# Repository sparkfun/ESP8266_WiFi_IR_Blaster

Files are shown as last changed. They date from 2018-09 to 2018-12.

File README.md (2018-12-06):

SparkFun WiFi IR Blaster (ESP8266)
========================================

SparkFun ESP8266 WiFi IR Blaster (https://www.sparkfun.com/products/15031)

[*SparkFun ESP8266 WiFi IR Blaster (DEV-15031)*](https://www.sparkfun.com/products/15031)

The WiFi IR Blaster is designed to connect all of your old, legacy IR-controlled devices to a WiFi network -- exposing them to a new method of control. Want to control your TV via a web-browser? Want to ask Alexa to mute your stereo? Want to schedule triggers to your IR-controlled LED strip? These are all applications that the WiFi IR Blaster is perfect for.

The WiFi IR Blaster combines an ESP8266 -- a powerful WiFi/microcontroller SoC -- with an IR emitter and receiver. With built-in WiFi support, the ESP8266 can be programmed to provide an interface between HTTP, MQTT, TCP, and UDP services and infrared-controlled devices.

This product includes the WiFi IR Blaster, a [Lite-ON LTE-302](https://www.sparkfun.com/datasheets/Components/LTE-302.pdf) infrared emitter, and a [TSOP38238 IR receiver](https://www.sparkfun.com/products/10266). The IR emitter and detector are not populated on the board -- allowing you to assemble them in any orientation your project requires.

For help getting started, check out our [WiFi IR Blaster Hookup Guide](https://learn.sparkfun.com/tutorials/wifi-ir-blaster-hookup-guide), which explains how to assemble the board, program it, and use the [IRremoteESP8266](https://github.com/markszabo/IRremoteESP8266) Arduino library.

SparkFun labored with love to create this code. Feel like supporting open source hardware? 
Buy a [breakout board](https://www.sparkfun.com/products/15000) from SparkFun!

Repository Contents
-------------------

* **/Documents** - Datasheets
* **/Hardware** - Eagle design files (.brd, .sch)
* **/Production** - Production panel files (.brd)

Documentation
--------------

* **[Hookup Guide](https://learn.sparkfun.com/tutorials/sparkfun-wifi-ir-blaster-hookup-guide)** - Basic hookup guide.

License Information
-------------------

This product is _**open source**_! 

If you have any questions or concerns on licensing, please contact techsupport@sparkfun.com.

Please use, reuse, and modify these files as you see fit. Please maintain attribution to SparkFun Electronics and release any derivative under the same license.

Distributed as-is; no warranty is given.

- Your friends at SparkFun.

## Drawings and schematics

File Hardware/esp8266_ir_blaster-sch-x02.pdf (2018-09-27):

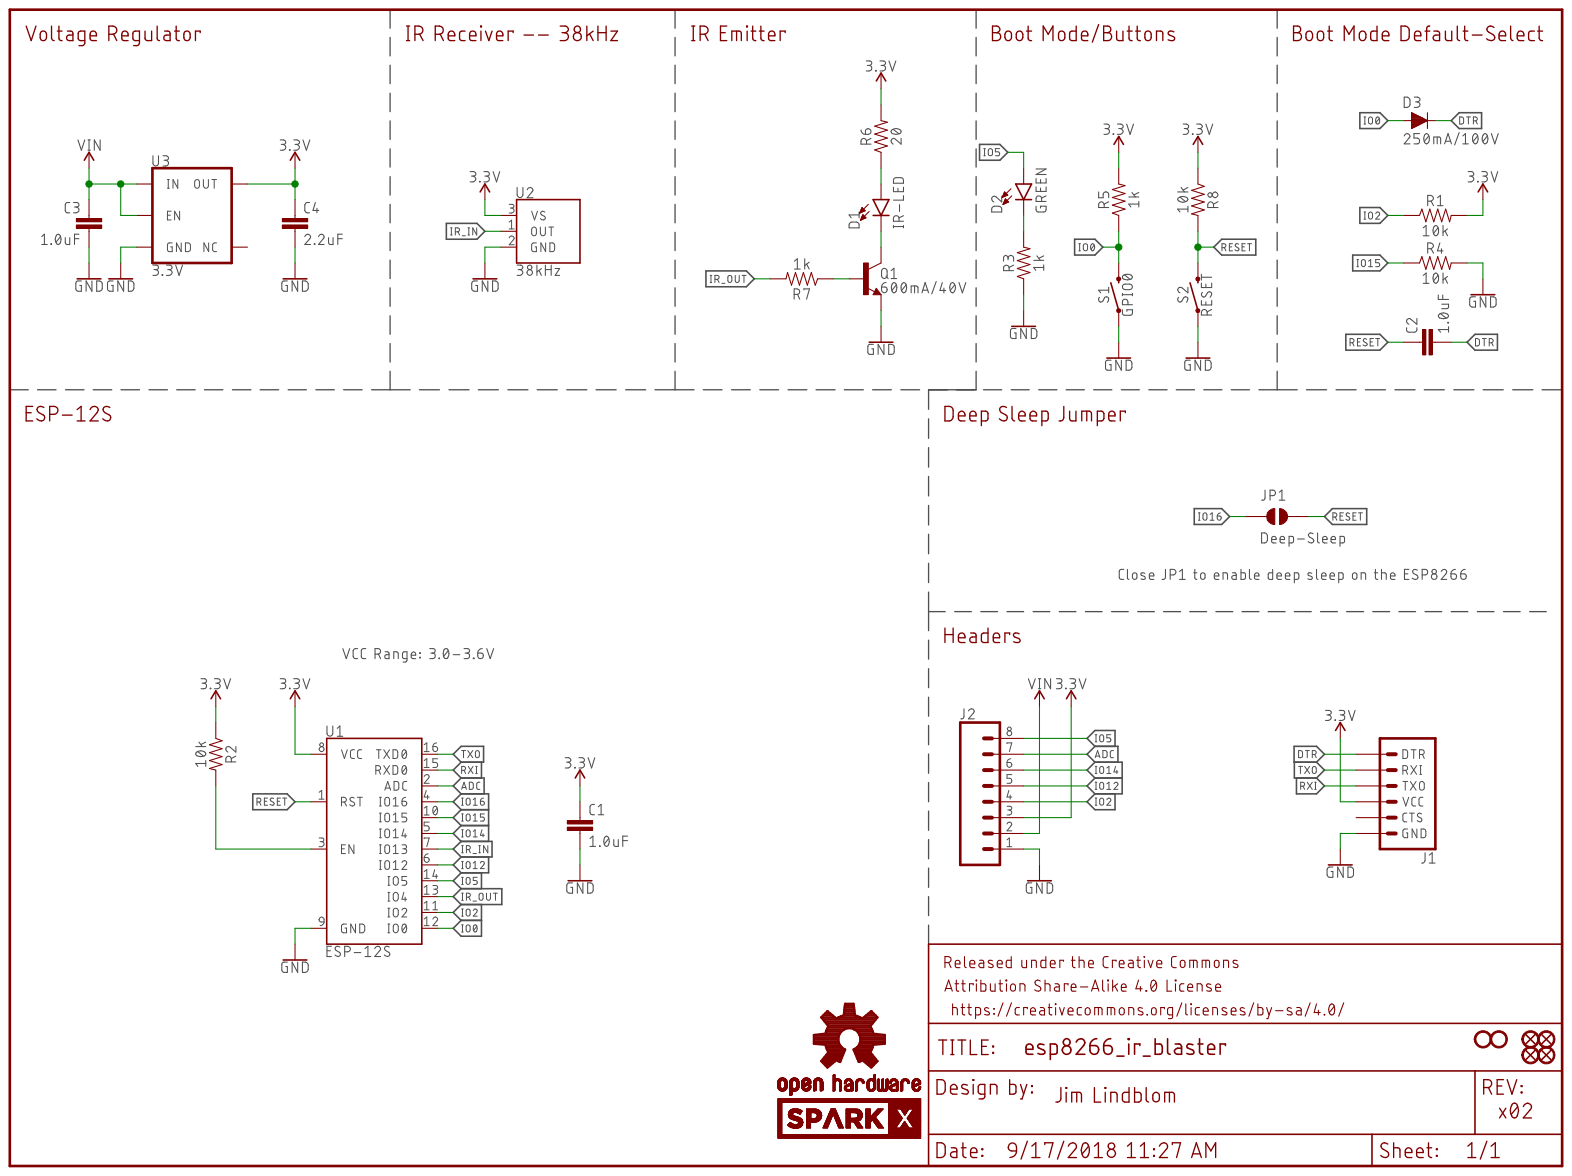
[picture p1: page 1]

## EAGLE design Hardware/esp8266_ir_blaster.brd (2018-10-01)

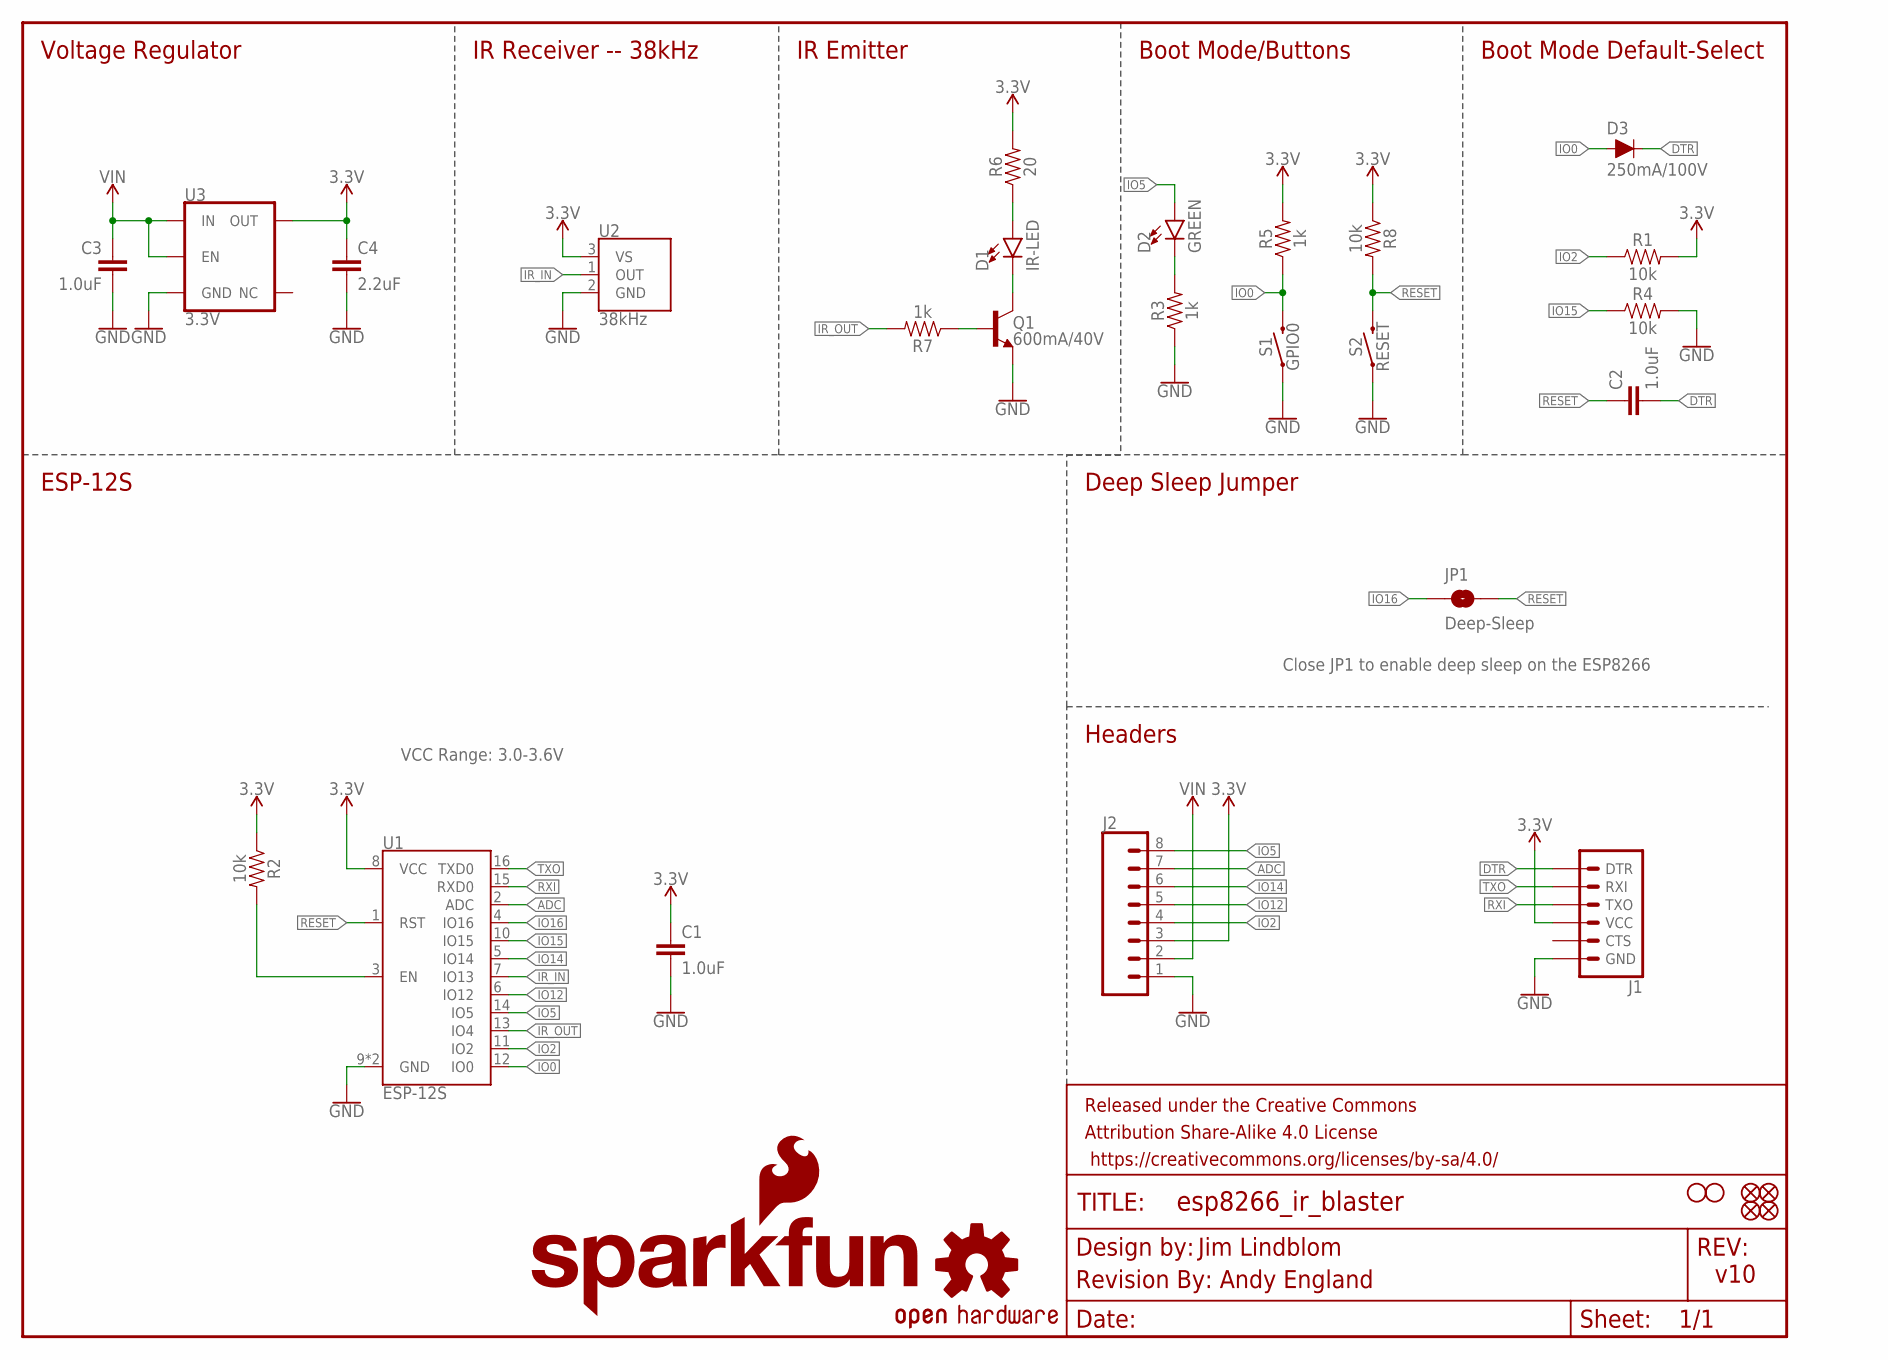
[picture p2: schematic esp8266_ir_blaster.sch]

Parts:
C1, C2, C3: 1.0uF; 0603
C4: 2.2uF; 0603
D1: IR-LED; LTE-302
D2: GREEN; LED-0603
D3: 250mA/100V; SOD-323
FD1, FD2, FD3, FD4: FIDUCIALUFIDUCIAL; FIDUCIAL-MICRO
FRAME1: FRAME-LETTER; CREATIVE_COMMONS
H1, H2: STAND-OFF
J1: 6_PIN_SERIAL_TARGETNO_SILK; 1X06_NO_SILK
J2: CONN_08NO_SILK_FEMALE_PTH; 1X08_NO_SILK
JP1: Deep-Sleep; SMT-JUMPER_2_NO_NO-SILK
LOGO1: OSHW-LOGOS; OSHW-LOGO-S
LOGO2: SFE_LOGO_NAME_FLAME.1_INCH; SFE_LOGO_NAME_FLAME_.1
LOGO3: REVISION
Q1: 600mA/40V; SOT23-3
R1, R2, R4, R8: 10k; 0603
R3, R5, R7: 1k; 0603
R6: 20; 0603
S1: GPIO0; TACTILE_SWITCH_SMD_4.6X2.8MM
S2: RESET; TACTILE_SWITCH_SMD_4.6X2.8MM
U1: ESP-12S
U2: 38kHz; TSOP382
U3: 3.3V; SOT23-5

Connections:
3.3V: C1.1, C4.1, J1.4 (VCC), J2.3, R1.2, R2.1, R5.2, R6.2, R8.1, U1.8 (VCC), U2.3 (VS), U3.5 (OUT)
ADC: J2.7, U1.2 (ADC)
CHIP_EN: R2.2, U1.3 (EN)
DTR: C2.2, D3.C, J1.1 (DTR)
GND: C1.2, C3.2, C4.2, J1.6 (GND), J2.1, Q1.2 (E), R3.1, R4.2, S1.1, S1.2 (1), S2.1, S2.2 (1), U1.9 (GND), U1.P$1 (GND), U2.2 (GND), U3.2 (GND)
IO0: D3.A, R5.1, S1.3 (2), S1.4 (2), U1.12 (IO0)
IO2: J2.4, R1.1, U1.11 (IO2)
IO5: D2.A, J2.8, U1.14 (IO5)
IO12: J2.5, U1.6 (IO12)
IO14: J2.6, U1.5 (IO14)
IO15: R4.1, U1.10 (IO15)
IO16: JP1.1, U1.4 (IO16)
IR_IN: U1.7 (IO13), U2.1 (OUT)
IR_OUT: R7.2, U1.13 (IO4)
unnamed: D2.C, R3.2
unnamed: D1.C, Q1.3 (C)
unnamed: D1.A, R6.1
unnamed: Q1.1 (B), R7.1
RESET: C2.1, JP1.2, R8.2, S2.3 (2), S2.4 (2), U1.1 (RST)
RXI: J1.3 (TXO), U1.15 (RXD0)
TXO: J1.2 (RXI), U1.16 (TXD0)
VIN: C3.1, J2.2, U3.1 (IN), U3.3 (EN)

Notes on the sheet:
Jim Lindblom
v10
IR Receiver -- 38kHz
IR Emitter
Boot Mode/Buttons
Boot Mode Default-Select
Deep Sleep Jumper
Headers
ESP-12S
Close JP1 to enable deep sleep on the ESP8266
VCC Range: 3.0-3.6V
Voltage Regulator
Andy England

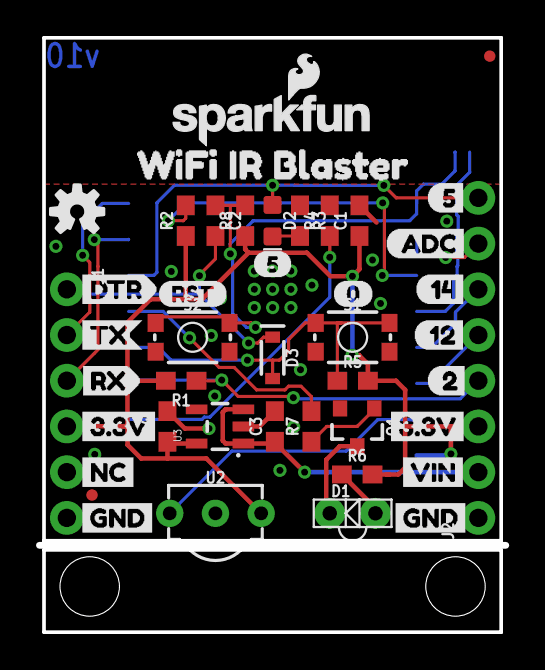
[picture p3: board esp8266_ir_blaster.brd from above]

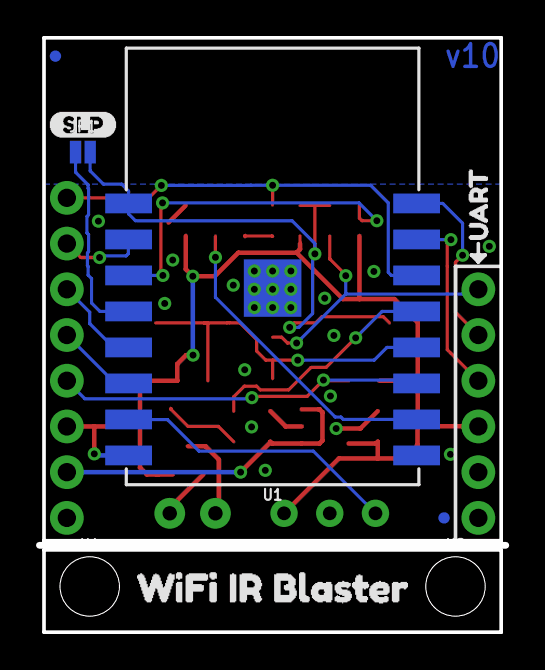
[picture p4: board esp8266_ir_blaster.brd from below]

Board: 2 copper layers, 25.9 x 33.0 mm, 55 parts (9 on the bottom side), 22 nets.

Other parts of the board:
U$1: 512
U$2, U$21: 3#3V4
U$3: SLP14
U$4, U$13: WIFI_IR_BLASTER11
U$5: UART0
U$6: DTR1
U$7: NC0
U$8: 511
U$9: ADC10
U$10: 129
U$11: 148
U$12: 27
U$14: 013
U$15: RST14
U$19: TX2
U$20: RX3
U$22, U$24: GND5
U$23: VIN6

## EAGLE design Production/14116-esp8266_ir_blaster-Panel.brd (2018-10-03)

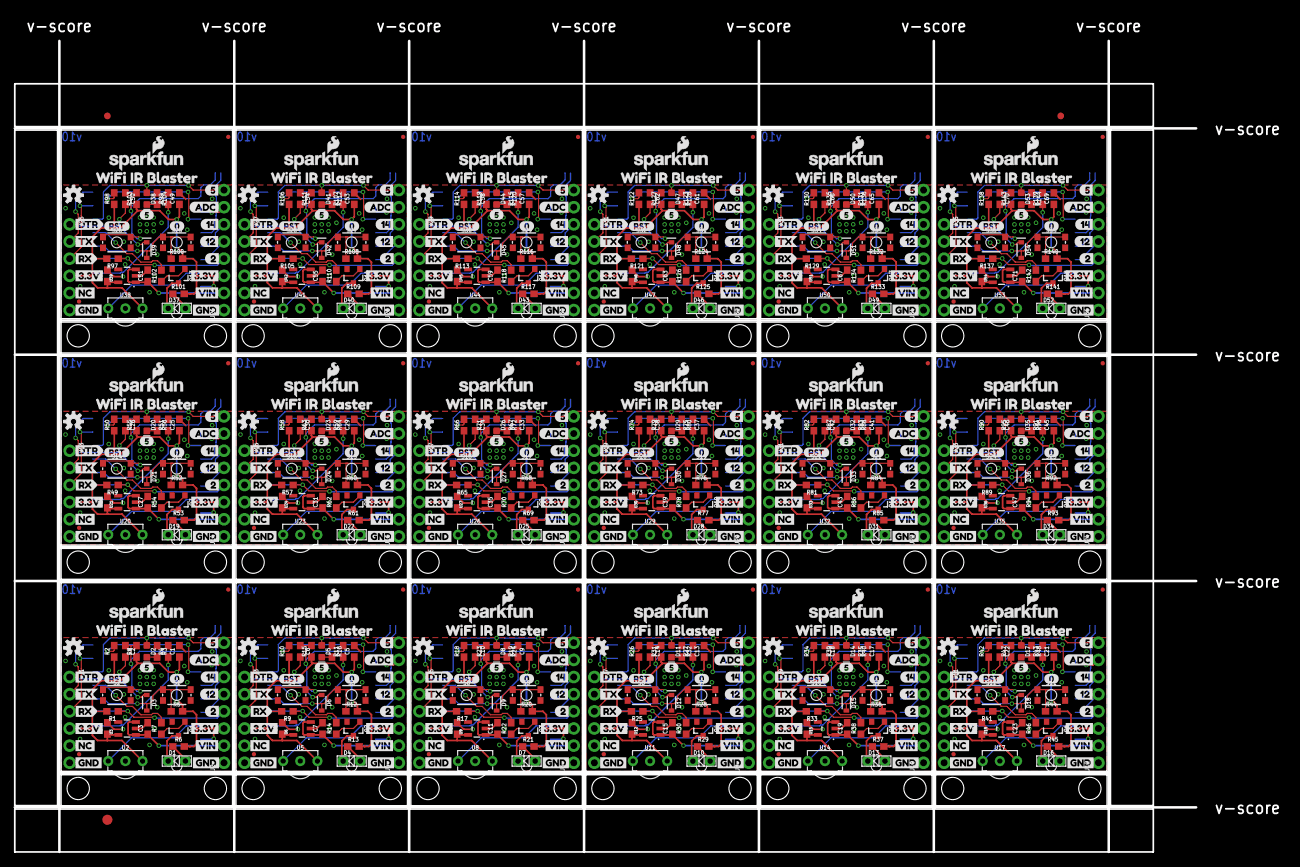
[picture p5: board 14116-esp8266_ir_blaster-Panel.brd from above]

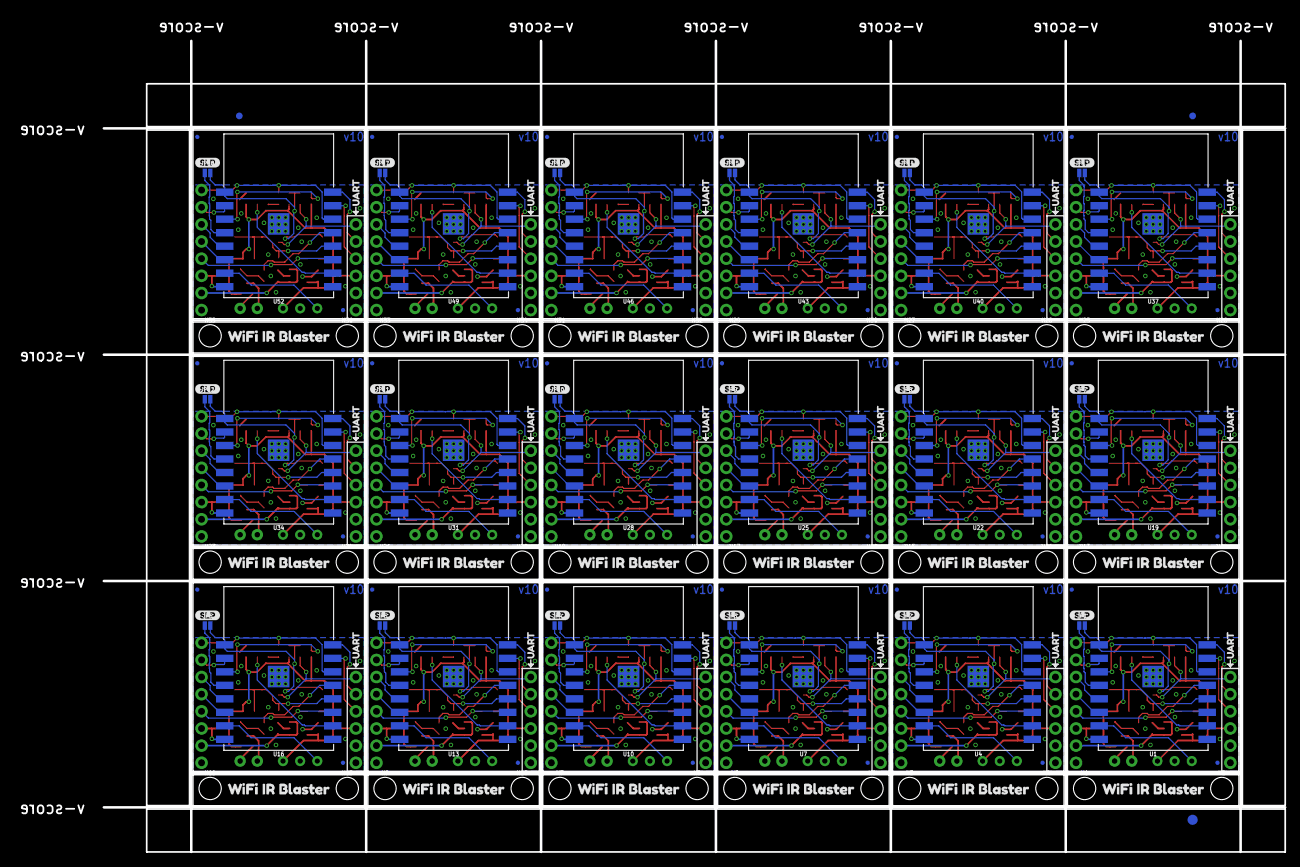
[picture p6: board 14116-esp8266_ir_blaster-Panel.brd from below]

Board: 2 copper layers, 175.0 x 120.1 mm, 960 parts (165 on the bottom side), 396 nets.

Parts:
C1, C2, C3, C5, C6, C7, C9, C10, C11, C13, C14, C15, C17, C18, C19, C21, C22, C23, C25, C26, C27, C29, C30, C31, C33, C34, C35, C37, C38, C39, C41, C42, C43, C45, C46, C47, C49, C50, C51, C53, C54, C55, C57, C58, C59, C61, C62, C63, C65, C66, C67, C69, C70, C71: 1.0uF; 0603
C4, C8, C12, C16, C20, C24, C28, C32, C36, C40, C44, C48, C52, C56, C60, C64, C68, C72: 2.2uF; 0603
D1, D4, D7, D10, D13, D16, D19, D22, D25, D28, D31, D34, D37, D40, D43, D46, D49, D52: IR-LED; LTE-302
D2, D5, D8, D11, D14, D17, D20, D23, D26, D29, D32, D35, D38, D41, D44, D47, D50, D53: GREEN; LED-0603
D3, D6, D9, D12, D15, D18, D21, D24, D27, D30, D33, D36, D39, D42, D45, D48, D51, D54: 250mA/100V; SOD-323
E$1, E$2, E$3, E$4: FIDUCIAL-1X2
E$5, E$6: FIDUCIAL-1.5X3
FD1, FD2, FD3, FD4, FD5, FD6, FD7, FD8, FD9, FD10, FD11, FD12, FD13, FD14, FD15, FD16, FD17, FD18, FD19, FD20, FD21, FD22, FD23, FD24, FD25, FD26, FD27, FD28, FD29, FD30, FD31, FD32, FD33, FD34, FD35, FD36, FD37, FD38, FD39, FD40, FD41, FD42, FD43, FD44, FD45, FD46, FD47, FD48, FD49, FD50, FD51, FD52, FD53, FD54, FD55, FD56, FD57, FD58, FD59, FD60, FD61, FD62, FD63, FD64, FD65, FD66, FD67, FD68, FD69, FD70, FD71, FD72: FIDUCIALUFIDUCIAL; FIDUCIAL-MICRO
H1, H2, H3, H4, H5, H6, H7, H8, H9, H10, H11, H12, H13, H14, H15, H16, H17, H18, H19, H20, H21, H22, H23, H24, H25, H26, H27, H28, H29, H30, H31, H32, H33, H34, H35, H36: STAND-OFF
J1, J3, J5, J7, J9, J11, J13, J15, J17, J19, J21, J23, J25, J27, J29, J31, J33, J35: 1X06_NO_SILK
J2, J4, J6, J8, J10, J12, J14, J16, J18, J20, J22, J24, J26, J28, J30, J32, J34, J36: 1X08_NO_SILK
JP1, JP2, JP3, JP4, JP5, JP6, JP7, JP8, JP9, JP10, JP11, JP12, JP13, JP14, JP15, JP16, JP17, JP18: Deep-Sleep; SMT-JUMPER_2_NO_NO-SILK
LOGO1, LOGO4, LOGO6, LOGO8, LOGO10, LOGO12, LOGO14, LOGO16, LOGO18, LOGO20, LOGO22, LOGO24, LOGO26, LOGO28, LOGO30, LOGO32, LOGO34, LOGO36: OSHW-LOGOS; OSHW-LOGO-S
LOGO2, LOGO3, LOGO5, LOGO7, LOGO9, LOGO11, LOGO13, LOGO15, LOGO17, LOGO19, LOGO21, LOGO23, LOGO25, LOGO27, LOGO29, LOGO31, LOGO33, LOGO35: SFE_LOGO_NAME_FLAME.1_INCH; SFE_LOGO_NAME_FLAME_.1
Q1, Q2, Q3, Q4, Q5, Q6, Q7, Q8, Q9, Q10, Q11, Q12, Q13, Q14, Q15, Q16, Q17, Q18: 600mA/40V; SOT23-3
R1, R2, R4, R8, R9, R10, R11, R15, R17, R18, R19, R23, R25, R26, R27, R31, R33, R34, R35, R39, R41, R42, R43, R47, R49, R50, R51, R55, R57, R58, R59, R63, R65, R66, R67, R71, R73, R74, R75, R79, R81, R82, R83, R87, R89, R90, R91, R95, R97, R98, R99, R103, R105, R106, R107, R111, R113, R114, R115, R119, R121, R122, R123, R127, R129, R130, R131, R135, R137, R138, R139, R143: 10k; 0603
R3, R5, R7, R12, R14, R16, R20, R22, R24, R28, R30, R32, R36, R38, R40, R44, R46, R48, R52, R54, R56, R60, R62, R64, R68, R70, R72, R76, R78, R80, R84, R86, R88, R92, R94, R96, R100, R102, R104, R108, R110, R112, R116, R118, R120, R124, R126, R128, R132, R134, R136, R140, R142, R144: 1k; 0603
R6, R13, R21, R29, R37, R45, R53, R61, R69, R77, R85, R93, R101, R109, R117, R125, R133, R141: 20; 0603
S1, S3, S5, S7, S9, S11, S13, S15, S17, S19, S21, S23, S25, S27, S29, S31, S33, S35: GPIO0; TACTILE_SWITCH_SMD_4.6X2.8MM
S2, S4, S6, S8, S10, S12, S14, S16, S18, S20, S22, S24, S26, S28, S30, S32, S34, S36: RESET; TACTILE_SWITCH_SMD_4.6X2.8MM
U1, U4, U7, U10, U13, U16, U19, U22, U25, U28, U31, U34, U37, U40, U43, U46, U49, U52: ESP-12S
U2, U5, U8, U11, U14, U17, U20, U23, U26, U29, U32, U35, U38, U41, U44, U47, U50, U53: 38kHz; TSOP382
U3, U6, U9, U12, U15, U18, U21, U24, U27, U30, U33, U36, U39, U42, U45, U48, U51, U54: 3.3V; SOT23-5
U$1, U$37, U$58, U$79, U$100, U$121, U$142, U$163, U$184, U$205, U$226, U$247, U$268, U$289, U$310, U$331, U$352, U$373: 512
U$2, U$21, U$28, U$38, U$49, U$59, U$70, U$80, U$91, U$101, U$112, U$122, U$133, U$143, U$154, U$164, U$175, U$185, U$196, U$206, U$217, U$227, U$238, U$248, U$259, U$269, U$280, U$290, U$301, U$311, U$322, U$332, U$343, U$353, U$364, U$374: 3#3V4
U$3, U$39, U$60, U$81, U$102, U$123, U$144, U$165, U$186, U$207, U$228, U$249, U$270, U$291, U$312, U$333, U$354, U$375: SLP14
U$4, U$13, U$16, U$40, U$43, U$61, U$64, U$82, U$85, U$103, U$106, U$124, U$127, U$145, U$148, U$166, U$169, U$187, U$190, U$208, U$211, U$229, U$232, U$250, U$253, U$271, U$274, U$292, U$295, U$313, U$316, U$334, U$337, U$355, U$358, U$376: WIFI_IR_BLASTER11
U$5, U$41, U$62, U$83, U$104, U$125, U$146, U$167, U$188, U$209, U$230, U$251, U$272, U$293, U$314, U$335, U$356, U$377: UART0
U$6, U$25, U$46, U$67, U$88, U$109, U$130, U$151, U$172, U$193, U$214, U$235, U$256, U$277, U$298, U$319, U$340, U$361: DTR1
U$7, U$42, U$63, U$84, U$105, U$126, U$147, U$168, U$189, U$210, U$231, U$252, U$273, U$294, U$315, U$336, U$357, U$378: NC0
U$8, U$30, U$51, U$72, U$93, U$114, U$135, U$156, U$177, U$198, U$219, U$240, U$261, U$282, U$303, U$324, U$345, U$366: 511
U$9, U$31, U$52, U$73, U$94, U$115, U$136, U$157, U$178, U$199, U$220, U$241, U$262, U$283, U$304, U$325, U$346, U$367: ADC10
U$10, U$32, U$53, U$74, U$95, U$116, U$137, U$158, U$179, U$200, U$221, U$242, U$263, U$284, U$305, U$326, U$347, U$368: 129
U$11, U$33, U$54, U$75, U$96, U$117, U$138, U$159, U$180, U$201, U$222, U$243, U$264, U$285, U$306, U$327, U$348, U$369: 148
U$12, U$34, U$55, U$76, U$97, U$118, U$139, U$160, U$181, U$202, U$223, U$244, U$265, U$286, U$307, U$328, U$349, U$370: 27
U$14, U$17, U$44, U$65, U$86, U$107, U$128, U$149, U$170, U$191, U$212, U$233, U$254, U$275, U$296, U$317, U$338, U$359: 013
U$15, U$18, U$45, U$66, U$87, U$108, U$129, U$150, U$171, U$192, U$213, U$234, U$255, U$276, U$297, U$318, U$339, U$360: RST14
U$19, U$26, U$47, U$68, U$89, U$110, U$131, U$152, U$173, U$194, U$215, U$236, U$257, U$278, U$299, U$320, U$341, U$362: TX2
U$20, U$27, U$48, U$69, U$90, U$111, U$132, U$153, U$174, U$195, U$216, U$237, U$258, U$279, U$300, U$321, U$342, U$363: RX3
U$22, U$24, U$29, U$36, U$50, U$57, U$71, U$78, U$92, U$99, U$113, U$120, U$134, U$141, U$155, U$162, U$176, U$183, U$197, U$204, U$218, U$225, U$239, U$246, U$260, U$267, U$281, U$288, U$302, U$309, U$323, U$330, U$344, U$351, U$365, U$372: GND5
U$23, U$35, U$56, U$77, U$98, U$119, U$140, U$161, U$182, U$203, U$224, U$245, U$266, U$287, U$308, U$329, U$350, U$371: VIN6

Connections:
3.3V: C1.1, C4.1, J1.4, J2.3, R1.2, R2.1, R5.2, R6.2, R8.1, U1.8, U2.3, U3.5
3.3V1: C5.1, C8.1, J3.4, J4.3, R9.2, R10.1, R12.2, R13.2, R15.1, U4.8, U5.3, U6.5
3.3V2: C9.1, C12.1, J5.4, J6.3, R17.2, R18.1, R20.2, R21.2, R23.1, U7.8, U8.3, U9.5
3.3V3: C13.1, C16.1, J7.4, J8.3, R25.2, R26.1, R28.2, R29.2, R31.1, U10.8, U11.3, U12.5
3.3V4: C17.1, C20.1, J9.4, J10.3, R33.2, R34.1, R36.2, R37.2, R39.1, U13.8, U14.3, U15.5
3.3V5: C21.1, C24.1, J11.4, J12.3, R41.2, R42.1, R44.2, R45.2, R47.1, U16.8, U17.3, U18.5
3.3V6: C25.1, C28.1, J13.4, J14.3, R49.2, R50.1, R52.2, R53.2, R55.1, U19.8, U20.3, U21.5
3.3V7: C29.1, C32.1, J15.4, J16.3, R57.2, R58.1, R60.2, R61.2, R63.1, U22.8, U23.3, U24.5
3.3V8: C33.1, C36.1, J17.4, J18.3, R65.2, R66.1, R68.2, R69.2, R71.1, U25.8, U26.3, U27.5
3.3V9: C37.1, C40.1, J19.4, J20.3, R73.2, R74.1, R76.2, R77.2, R79.1, U28.8, U29.3, U30.5
3.3V10: C41.1, C44.1, J21.4, J22.3, R81.2, R82.1, R84.2, R85.2, R87.1, U31.8, U32.3, U33.5
3.3V11: C45.1, C48.1, J23.4, J24.3, R89.2, R90.1, R92.2, R93.2, R95.1, U34.8, U35.3, U36.5
3.3V12: C49.1, C52.1, J25.4, J26.3, R97.2, R98.1, R100.2, R101.2, R103.1, U37.8, U38.3, U39.5
3.3V13: C53.1, C56.1, J27.4, J28.3, R105.2, R106.1, R108.2, R109.2, R111.1, U40.8, U41.3, U42.5
3.3V14: C57.1, C60.1, J29.4, J30.3, R113.2, R114.1, R116.2, R117.2, R119.1, U43.8, U44.3, U45.5
3.3V15: C61.1, C64.1, J31.4, J32.3, R121.2, R122.1, R124.2, R125.2, R127.1, U46.8, U47.3, U48.5
3.3V16: C65.1, C68.1, J33.4, J34.3, R129.2, R130.1, R132.2, R133.2, R135.1, U49.8, U50.3, U51.5
3.3V17: C69.1, C72.1, J35.4, J36.3, R137.2, R138.1, R140.2, R141.2, R143.1, U52.8, U53.3, U54.5
ADC: J2.7, U1.2
ADC1: J4.7, U4.2
ADC2: J6.7, U7.2
ADC3: J8.7, U10.2
ADC4: J10.7, U13.2
ADC5: J12.7, U16.2
ADC6: J14.7, U19.2
ADC7: J16.7, U22.2
ADC8: J18.7, U25.2
ADC9: J20.7, U28.2
ADC10: J22.7, U31.2
ADC11: J24.7, U34.2
ADC12: J26.7, U37.2
ADC13: J28.7, U40.2
ADC14: J30.7, U43.2
ADC15: J32.7, U46.2
ADC16: J34.7, U49.2
ADC17: J36.7, U52.2
CHIP_EN: R2.2, U1.3
CHIP_EN1: R10.2, U4.3
CHIP_EN2: R18.2, U7.3
CHIP_EN3: R26.2, U10.3
CHIP_EN4: R34.2, U13.3
CHIP_EN5: R42.2, U16.3
CHIP_EN6: R50.2, U19.3
CHIP_EN7: R58.2, U22.3
CHIP_EN8: R66.2, U25.3
CHIP_EN9: R74.2, U28.3
CHIP_EN10: R82.2, U31.3
CHIP_EN11: R90.2, U34.3
CHIP_EN12: R98.2, U37.3
CHIP_EN13: R106.2, U40.3
CHIP_EN14: R114.2, U43.3
CHIP_EN15: R122.2, U46.3
CHIP_EN16: R130.2, U49.3
CHIP_EN17: R138.2, U52.3
DTR: C2.2, D3.C, J1.1
DTR1: C6.2, D6.C, J3.1
DTR2: C10.2, D9.C, J5.1
DTR3: C14.2, D12.C, J7.1
DTR4: C18.2, D15.C, J9.1
DTR5: C22.2, D18.C, J11.1
DTR6: C26.2, D21.C, J13.1
DTR7: C30.2, D24.C, J15.1
DTR8: C34.2, D27.C, J17.1
DTR9: C38.2, D30.C, J19.1
DTR10: C42.2, D33.C, J21.1
DTR11: C46.2, D36.C, J23.1
DTR12: C50.2, D39.C, J25.1
DTR13: C54.2, D42.C, J27.1
DTR14: C58.2, D45.C, J29.1
DTR15: C62.2, D48.C, J31.1
DTR16: C66.2, D51.C, J33.1
DTR17: C70.2, D54.C, J35.1
GND: C1.2, C3.2, C4.2, J1.6, J2.1, Q1.2, R3.1, R4.2, S1.1, S1.2, S2.1, S2.2, U1.9, U1.P$1, U2.2, U3.2
GND1: C5.2, C7.2, C8.2, J3.6, J4.1, Q2.2, R11.2, R16.1, S3.1, S3.2, S4.1, S4.2, U4.9, U4.P$1, U5.2, U6.2
GND2: C9.2, C11.2, C12.2, J5.6, J6.1, Q3.2, R19.2, R24.1, S5.1, S5.2, S6.1, S6.2, U7.9, U7.P$1, U8.2, U9.2
GND3: C13.2, C15.2, C16.2, J7.6, J8.1, Q4.2, R27.2, R32.1, S7.1, S7.2, S8.1, S8.2, U10.9, U10.P$1, U11.2, U12.2
GND4: C17.2, C19.2, C20.2, J9.6, J10.1, Q5.2, R35.2, R40.1, S9.1, S9.2, S10.1, S10.2, U13.9, U13.P$1, U14.2, U15.2
GND5: C21.2, C23.2, C24.2, J11.6, J12.1, Q6.2, R43.2, R48.1, S11.1, S11.2, S12.1, S12.2, U16.9, U16.P$1, U17.2, U18.2
GND6: C25.2, C27.2, C28.2, J13.6, J14.1, Q7.2, R51.2, R56.1, S13.1, S13.2, S14.1, S14.2, U19.9, U19.P$1, U20.2, U21.2
GND7: C29.2, C31.2, C32.2, J15.6, J16.1, Q8.2, R59.2, R64.1, S15.1, S15.2, S16.1, S16.2, U22.9, U22.P$1, U23.2, U24.2
GND8: C33.2, C35.2, C36.2, J17.6, J18.1, Q9.2, R67.2, R72.1, S17.1, S17.2, S18.1, S18.2, U25.9, U25.P$1, U26.2, U27.2
GND9: C37.2, C39.2, C40.2, J19.6, J20.1, Q10.2, R75.2, R80.1, S19.1, S19.2, S20.1, S20.2, U28.9, U28.P$1, U29.2, U30.2
GND10: C41.2, C43.2, C44.2, J21.6, J22.1, Q11.2, R83.2, R88.1, S21.1, S21.2, S22.1, S22.2, U31.9, U31.P$1, U32.2, U33.2
GND11: C45.2, C47.2, C48.2, J23.6, J24.1, Q12.2, R91.2, R96.1, S23.1, S23.2, S24.1, S24.2, U34.9, U34.P$1, U35.2, U36.2
GND12: C49.2, C51.2, C52.2, J25.6, J26.1, Q13.2, R99.2, R104.1, S25.1, S25.2, S26.1, S26.2, U37.9, U37.P$1, U38.2, U39.2
GND13: C53.2, C55.2, C56.2, J27.6, J28.1, Q14.2, R107.2, R112.1, S27.1, S27.2, S28.1, S28.2, U40.9, U40.P$1, U41.2, U42.2
GND14: C57.2, C59.2, C60.2, J29.6, J30.1, Q15.2, R115.2, R120.1, S29.1, S29.2, S30.1, S30.2, U43.9, U43.P$1, U44.2, U45.2
GND15: C61.2, C63.2, C64.2, J31.6, J32.1, Q16.2, R123.2, R128.1, S31.1, S31.2, S32.1, S32.2, U46.9, U46.P$1, U47.2, U48.2
GND16: C65.2, C67.2, C68.2, J33.6, J34.1, Q17.2, R131.2, R136.1, S33.1, S33.2, S34.1, S34.2, U49.9, U49.P$1, U50.2, U51.2
GND17: C69.2, C71.2, C72.2, J35.6, J36.1, Q18.2, R139.2, R144.1, S35.1, S35.2, S36.1, S36.2, U52.9, U52.P$1, U53.2, U54.2
IO0: D3.A, R5.1, S1.3, S1.4, U1.12
IO1: R11.1, U4.10
IO2: J2.4, R1.1, U1.11
IO3: J4.4, R9.1, U4.11
IO4: D6.A, R12.1, S3.3, S3.4, U4.12
IO5: D2.A, J2.8, U1.14
IO6: J4.6, U4.5
IO7: JP2.1, U4.4
IO8: J4.5, U4.6
IO9: D5.A, J4.8, U4.14
IO10: R19.1, U7.10
IO11: J6.4, R17.1, U7.11
IO12: J2.5, U1.6
IO13: D9.A, R20.1, S5.3, S5.4, U7.12
IO14: J2.6, U1.5
IO15: R4.1, U1.10
IO16: JP1.1, U1.4
IO17: J6.6, U7.5
IO18: JP3.1, U7.4
IO19: J6.5, U7.6
IO20: D8.A, J6.8, U7.14
IO21: R27.1, U10.10
IO22: J8.4, R25.1, U10.11
IO23: D12.A, R28.1, S7.3, S7.4, U10.12
IO24: J8.6, U10.5
IO25: JP4.1, U10.4
IO26: J8.5, U10.6
IO27: D11.A, J8.8, U10.14
IO28: R35.1, U13.10
IO29: J10.4, R33.1, U13.11
IO30: D15.A, R36.1, S9.3, S9.4, U13.12
IO31: J10.6, U13.5
IO32: JP5.1, U13.4
IO33: J10.5, U13.6
IO34: D14.A, J10.8, U13.14
IO35: R43.1, U16.10
IO36: J12.4, R41.1, U16.11
IO37: D18.A, R44.1, S11.3, S11.4, U16.12
IO38: J12.6, U16.5
IO39: JP6.1, U16.4
IO40: J12.5, U16.6
IO41: D17.A, J12.8, U16.14
IO42: R51.1, U19.10
IO43: J14.4, R49.1, U19.11
IO44: D21.A, R52.1, S13.3, S13.4, U19.12
IO45: J14.6, U19.5
IO46: JP7.1, U19.4
IO47: J14.5, U19.6
IO48: D20.A, J14.8, U19.14
IO49: R59.1, U22.10
IO50: J16.4, R57.1, U22.11
IO51: D24.A, R60.1, S15.3, S15.4, U22.12
IO52: J16.6, U22.5
IO53: JP8.1, U22.4
IO54: J16.5, U22.6
IO55: D23.A, J16.8, U22.14
IO56: R67.1, U25.10
IO57: J18.4, R65.1, U25.11
IO58: D27.A, R68.1, S17.3, S17.4, U25.12
IO59: J18.6, U25.5
IO60: JP9.1, U25.4
IO61: J18.5, U25.6
IO62: D26.A, J18.8, U25.14
IO63: R75.1, U28.10
IO64: J20.4, R73.1, U28.11
IO65: D30.A, R76.1, S19.3, S19.4, U28.12
IO66: J20.6, U28.5
IO67: JP10.1, U28.4
IO68: J20.5, U28.6
IO69: D29.A, J20.8, U28.14
IO70: R83.1, U31.10
IO71: J22.4, R81.1, U31.11
IO72: D33.A, R84.1, S21.3, S21.4, U31.12
IO73: J22.6, U31.5
IO74: JP11.1, U31.4
IO75: J22.5, U31.6
IO76: D32.A, J22.8, U31.14
IO77: R91.1, U34.10
IO78: J24.4, R89.1, U34.11
IO79: D36.A, R92.1, S23.3, S23.4, U34.12
IO80: J24.6, U34.5
IO81: JP12.1, U34.4
IO82: J24.5, U34.6
IO83: D35.A, J24.8, U34.14
IO84: R99.1, U37.10
IO85: J26.4, R97.1, U37.11
IO86: D39.A, R100.1, S25.3, S25.4, U37.12
IO87: J26.6, U37.5
IO88: JP13.1, U37.4
IO89: J26.5, U37.6
IO90: D38.A, J26.8, U37.14
IO91: R107.1, U40.10
IO92: J28.4, R105.1, U40.11
IO93: D42.A, R108.1, S27.3, S27.4, U40.12
IO94: J28.6, U40.5
IO95: JP14.1, U40.4
IO96: J28.5, U40.6
IO97: D41.A, J28.8, U40.14
IO98: R115.1, U43.10
IO99: J30.4, R113.1, U43.11
IO100: D45.A, R116.1, S29.3, S29.4, U43.12
IO101: J30.6, U43.5
IO102: JP15.1, U43.4
IO103: J30.5, U43.6
IO104: D44.A, J30.8, U43.14
IO105: R123.1, U46.10
IO106: J32.4, R121.1, U46.11
IO107: D48.A, R124.1, S31.3, S31.4, U46.12
IO108: J32.6, U46.5
IO109: JP16.1, U46.4
IO110: J32.5, U46.6
IO111: D47.A, J32.8, U46.14
IO112: R131.1, U49.10
IO113: J34.4, R129.1, U49.11
IO114: D51.A, R132.1, S33.3, S33.4, U49.12
IO115: J34.6, U49.5
IO116: JP17.1, U49.4
IO117: J34.5, U49.6
IO118: D50.A, J34.8, U49.14
IO119: R139.1, U52.10
IO120: J36.4, R137.1, U52.11
IO121: D54.A, R140.1, S35.3, S35.4, U52.12
IO122: J36.6, U52.5
IO123: JP18.1, U52.4
IO124: J36.5, U52.6
IO125: D53.A, J36.8, U52.14
IR_IN: U1.7, U2.1
IR_IN1: U4.7, U5.1
IR_IN2: U7.7, U8.1
IR_IN3: U10.7, U11.1
IR_IN4: U13.7, U14.1
IR_IN5: U16.7, U17.1
IR_IN6: U19.7, U20.1
IR_IN7: U22.7, U23.1
IR_IN8: U25.7, U26.1
IR_IN9: U28.7, U29.1
IR_IN10: U31.7, U32.1
IR_IN11: U34.7, U35.1
IR_IN12: U37.7, U38.1
IR_IN13: U40.7, U41.1
IR_IN14: U43.7, U44.1
IR_IN15: U46.7, U47.1
IR_IN16: U49.7, U50.1
IR_IN17: U52.7, U53.1
IR_OUT: R7.2, U1.13
IR_OUT1: R14.2, U4.13
IR_OUT2: R22.2, U7.13
IR_OUT3: R30.2, U10.13
IR_OUT4: R38.2, U13.13
IR_OUT5: R46.2, U16.13
IR_OUT6: R54.2, U19.13
IR_OUT7: R62.2, U22.13
IR_OUT8: R70.2, U25.13
IR_OUT9: R78.2, U28.13
IR_OUT10: R86.2, U31.13
IR_OUT11: R94.2, U34.13
IR_OUT12: R102.2, U37.13
IR_OUT13: R110.2, U40.13
IR_OUT14: R118.2, U43.13
IR_OUT15: R126.2, U46.13
IR_OUT16: R134.2, U49.13
IR_OUT17: R142.2, U52.13
unnamed: D2.C, R3.2
unnamed: D4.C, Q2.3
unnamed: D4.A, R13.1
unnamed: Q2.1, R14.1
unnamed: D1.C, Q1.3
unnamed: D1.A, R6.1
unnamed: Q1.1, R7.1
unnamed: D5.C, R16.2
unnamed: D7.C, Q3.3
unnamed: D7.A, R21.1
unnamed: Q3.1, R22.1
unnamed: D8.C, R24.2
unnamed: D10.C, Q4.3
unnamed: D10.A, R29.1
unnamed: Q4.1, R30.1
unnamed: D11.C, R32.2
unnamed: D13.C, Q5.3
unnamed: D13.A, R37.1
unnamed: Q5.1, R38.1
unnamed: D14.C, R40.2
unnamed: D16.C, Q6.3
unnamed: D16.A, R45.1
unnamed: Q6.1, R46.1
unnamed: D17.C, R48.2
unnamed: D19.C, Q7.3
unnamed: D19.A, R53.1
unnamed: Q7.1, R54.1
unnamed: D20.C, R56.2
unnamed: D22.C, Q8.3
unnamed: D22.A, R61.1
unnamed: Q8.1, R62.1
unnamed: D23.C, R64.2
unnamed: D25.C, Q9.3
unnamed: D25.A, R69.1
unnamed: Q9.1, R70.1
unnamed: D26.C, R72.2
unnamed: D28.C, Q10.3
unnamed: D28.A, R77.1
unnamed: Q10.1, R78.1
unnamed: D29.C, R80.2
unnamed: D31.C, Q11.3
unnamed: D31.A, R85.1
unnamed: Q11.1, R86.1
unnamed: D32.C, R88.2
unnamed: D34.C, Q12.3
unnamed: D34.A, R93.1
unnamed: Q12.1, R94.1
unnamed: D35.C, R96.2
unnamed: D37.C, Q13.3
unnamed: D37.A, R101.1
unnamed: Q13.1, R102.1
unnamed: D38.C, R104.2
unnamed: D40.C, Q14.3
unnamed: D40.A, R109.1
unnamed: Q14.1, R110.1
unnamed: D41.C, R112.2
unnamed: D43.C, Q15.3
unnamed: D43.A, R117.1
unnamed: Q15.1, R118.1
unnamed: D44.C, R120.2
unnamed: D46.C, Q16.3
unnamed: D46.A, R125.1
unnamed: Q16.1, R126.1
unnamed: D47.C, R128.2
unnamed: D49.C, Q17.3
unnamed: D49.A, R133.1
unnamed: Q17.1, R134.1
unnamed: D50.C, R136.2
unnamed: D52.C, Q18.3
unnamed: D52.A, R141.1
unnamed: Q18.1, R142.1
unnamed: D53.C, R144.2
RESET: C2.1, JP1.2, R8.2, S2.3, S2.4, U1.1
RESET1: C6.1, JP2.2, R15.2, S4.3, S4.4, U4.1
RESET2: C10.1, JP3.2, R23.2, S6.3, S6.4, U7.1
RESET3: C14.1, JP4.2, R31.2, S8.3, S8.4, U10.1
RESET4: C18.1, JP5.2, R39.2, S10.3, S10.4, U13.1
RESET5: C22.1, JP6.2, R47.2, S12.3, S12.4, U16.1
RESET6: C26.1, JP7.2, R55.2, S14.3, S14.4, U19.1
RESET7: C30.1, JP8.2, R63.2, S16.3, S16.4, U22.1
RESET8: C34.1, JP9.2, R71.2, S18.3, S18.4, U25.1
RESET9: C38.1, JP10.2, R79.2, S20.3, S20.4, U28.1
RESET10: C42.1, JP11.2, R87.2, S22.3, S22.4, U31.1
RESET11: C46.1, JP12.2, R95.2, S24.3, S24.4, U34.1
RESET12: C50.1, JP13.2, R103.2, S26.3, S26.4, U37.1
RESET13: C54.1, JP14.2, R111.2, S28.3, S28.4, U40.1
RESET14: C58.1, JP15.2, R119.2, S30.3, S30.4, U43.1
RESET15: C62.1, JP16.2, R127.2, S32.3, S32.4, U46.1
RESET16: C66.1, JP17.2, R135.2, S34.3, S34.4, U49.1
RESET17: C70.1, JP18.2, R143.2, S36.3, S36.4, U52.1
RXI: J1.3, U1.15
RXI1: J3.3, U4.15
RXI2: J5.3, U7.15
RXI3: J7.3, U10.15
RXI4: J9.3, U13.15
RXI5: J11.3, U16.15
RXI6: J13.3, U19.15
RXI7: J15.3, U22.15
RXI8: J17.3, U25.15
RXI9: J19.3, U28.15
RXI10: J21.3, U31.15
RXI11: J23.3, U34.15
RXI12: J25.3, U37.15
RXI13: J27.3, U40.15
RXI14: J29.3, U43.15
RXI15: J31.3, U46.15
RXI16: J33.3, U49.15
RXI17: J35.3, U52.15
TXO: J1.2, U1.16
TXO1: J3.2, U4.16
TXO2: J5.2, U7.16
TXO3: J7.2, U10.16
TXO4: J9.2, U13.16
TXO5: J11.2, U16.16
TXO6: J13.2, U19.16
TXO7: J15.2, U22.16
TXO8: J17.2, U25.16
TXO9: J19.2, U28.16
TXO10: J21.2, U31.16
TXO11: J23.2, U34.16
TXO12: J25.2, U37.16
TXO13: J27.2, U40.16
TXO14: J29.2, U43.16
TXO15: J31.2, U46.16
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

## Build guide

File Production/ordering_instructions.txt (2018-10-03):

panel size, 169x114mm
PCB thickness, 1.6mm
number of layers, 2
soldermask color, Red
silkscreen color, White
oz copper, 1oz
finish, HASL lead free
stencils, none
pcs per panel, 18

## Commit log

2018-09-27 Adding thermal pad
    [esp8266_ir_blaster.brd, esp8266_ir_blaster.sch]
2018-09-28 updating to reds
    [esp8266_ir_blaster.brd]
2018-10-01 post checklist changes
    [esp8266_ir_blaster.brd, esp8266_ir_blaster.sch]
2018-10-02 adding vin ranges
    [esp8266_ir_blaster.sch]
2018-10-03 panel v10 created
    [14116-esp8266_ir_blaster-Panel.GBL, 14116-esp8266_ir_blaster-Panel.GBO, 14116-esp8266_ir_blaster-Panel.GBP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]

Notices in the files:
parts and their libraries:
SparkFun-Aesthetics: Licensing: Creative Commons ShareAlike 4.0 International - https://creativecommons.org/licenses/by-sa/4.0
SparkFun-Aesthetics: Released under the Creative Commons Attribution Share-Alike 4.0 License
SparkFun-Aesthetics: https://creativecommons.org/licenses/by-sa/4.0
